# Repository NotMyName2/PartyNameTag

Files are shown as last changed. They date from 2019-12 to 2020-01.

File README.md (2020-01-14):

# PartyNameTag

Remember the nasty sticky paper name tags probably used at parties? Never been to any party, so I do not. Anyway, once I figure out how to put this thingy on a shirt, it can be used as a name tag.

The device can display any reasonably long message consisting of the characters in the English alphabet sent by Bluetooth from any smartphone(tested only on android). The text shifts in the same way like a "breaking news" row in the news.

In the future, I might add more functionality:

 	 *display a hard-coded message after a certain period of inactivity
        (You can ask for a girl's number this way :O )

  	*display random noise(partially done)

  	*up- and down-shifting

  	*finish the character lookup table

  	*implement the LED indicator for low battery

  	*display special emoji or animations

The thingy is based on Arduino Pro Mini, an AT09 Bluetooth module, a TC4056 Li-ion charger module, an old phone battery, 74HC595 shift registers, a DC-DC 5V voltage supply and many unipolar transistors.

The microcontroller can be easily reprogrammed using the Arduino IDE and a USB to Serial converter.

The custom PCB is in the "DivineMessengerBoard" directory. The smallest track width is 0.4mm and the smallest clearance is 0.2mm and is meant to be manufactured professionally (DIY drill or UV would probably bring frustration)

See the video at https://youtu.be/IolG6l6WMoY

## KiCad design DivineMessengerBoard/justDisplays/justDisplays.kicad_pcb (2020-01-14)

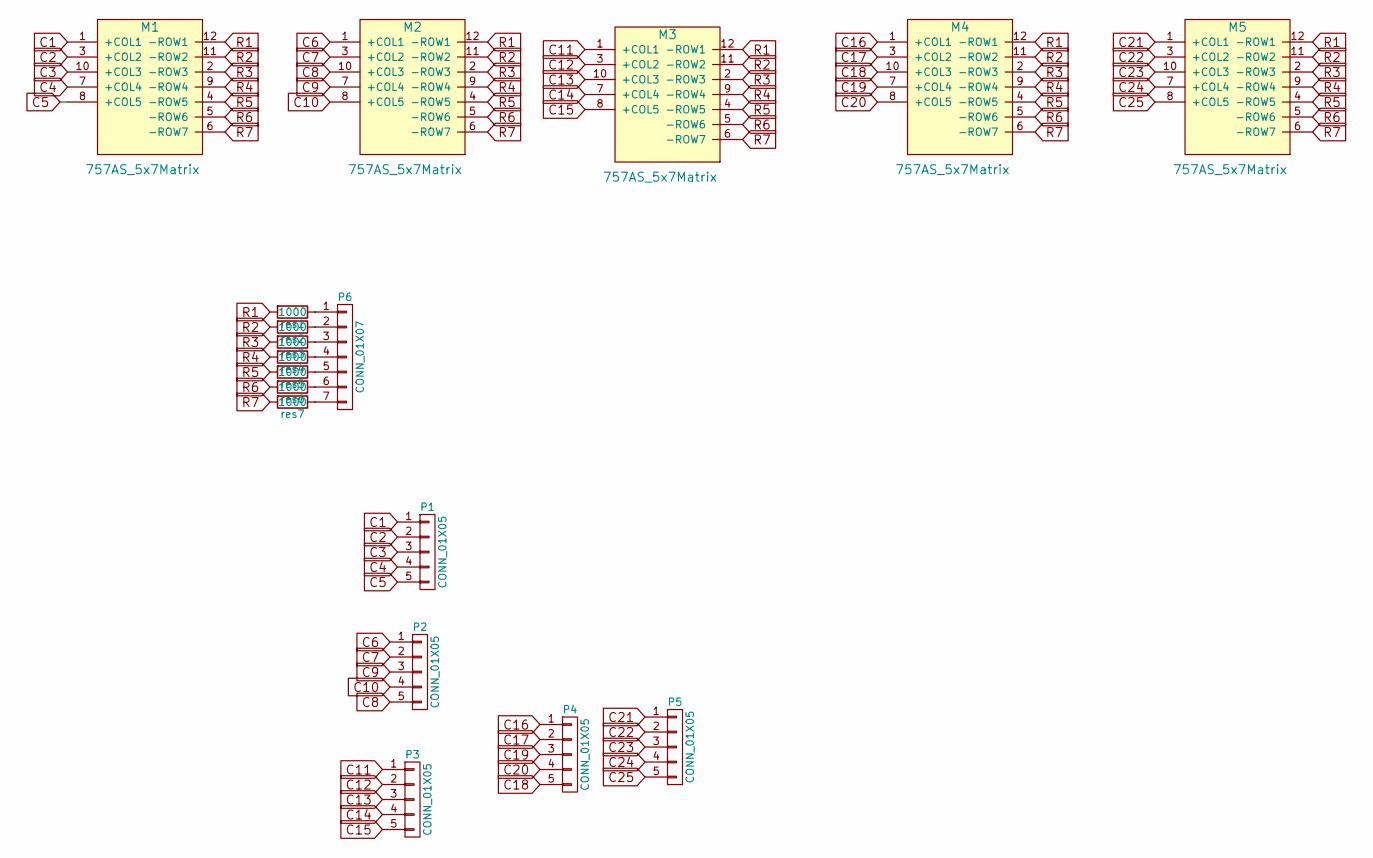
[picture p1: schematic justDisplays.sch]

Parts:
M1, M2, M3, M4, M5: 757AS_5x7Matrix; 757-5x7Matrix-socket
P1, P2, P3, P4, P5: CONN_01X05; NonRetardHeader1x5
P6: CONN_01X07; NonRetardHeader1x7
res1, res2, res3, res4, res5, res6, res7: 1000; R_1206_HandSoldering

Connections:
C1: M1.1 (+COL1), P1.1
C2: M1.3 (+COL2), P1.2
C3: M1.10 (+COL3), P1.3
C4: M1.7 (+COL4), P1.4
C5: M1.8 (+COL5), P1.5
C6: M2.1 (+COL1), P2.1
C7: M2.3 (+COL2), P2.2
C8: M2.10 (+COL3), P2.5
C9: M2.7 (+COL4), P2.3
C10: M2.8 (+COL5), P2.4
C11: M3.1 (+COL1), P3.1
C12: M3.3 (+COL2), P3.2
C13: M3.10 (+COL3), P3.3
C14: M3.7 (+COL4), P3.4
C15: M3.8 (+COL5), P3.5
C16: M4.1 (+COL1), P4.1
C17: M4.3 (+COL2), P4.2
C18: M4.10 (+COL3), P4.5
C19: M4.7 (+COL4), P4.3
C20: M4.8 (+COL5), P4.4
C21: M5.1 (+COL1), P5.1
C22: M5.3 (+COL2), P5.2
C23: M5.10 (+COL3), P5.3
C24: M5.7 (+COL4), P5.4
C25: M5.8 (+COL5), P5.5
unnamed: P6.1, res1.1
unnamed: P6.2, res2.1
unnamed: P6.3, res3.1
unnamed: P6.4, res4.1
unnamed: P6.5, res5.1
unnamed: P6.6, res6.1
unnamed: P6.7, res7.1
R1: M1.12 (-ROW1), M2.12 (-ROW1), M3.12 (-ROW1), M4.12 (-ROW1), M5.12 (-ROW1), res1.2
R2: M1.11 (-ROW2), M2.11 (-ROW2), M3.11 (-ROW2), M4.11 (-ROW2), M5.11 (-ROW2), res2.2
R3: M1.2 (-ROW3), M2.2 (-ROW3), M3.2 (-ROW3), M4.2 (-ROW3), M5.2 (-ROW3), res3.2
R4: M1.9 (-ROW4), M2.9 (-ROW4), M3.9 (-ROW4), M4.9 (-ROW4), M5.9 (-ROW4), res4.2
R5: M1.4 (-ROW5), M2.4 (-ROW5), M3.4 (-ROW5), M4.4 (-ROW5), M5.4 (-ROW5), res5.2
R6: M1.5 (-ROW6), M2.5 (-ROW6), M3.5 (-ROW6), M4.5 (-ROW6), M5.5 (-ROW6), res6.2
R7: M1.6 (-ROW7), M2.6 (-ROW7), M3.6 (-ROW7), M4.6 (-ROW7), M5.6 (-ROW7), res7.2

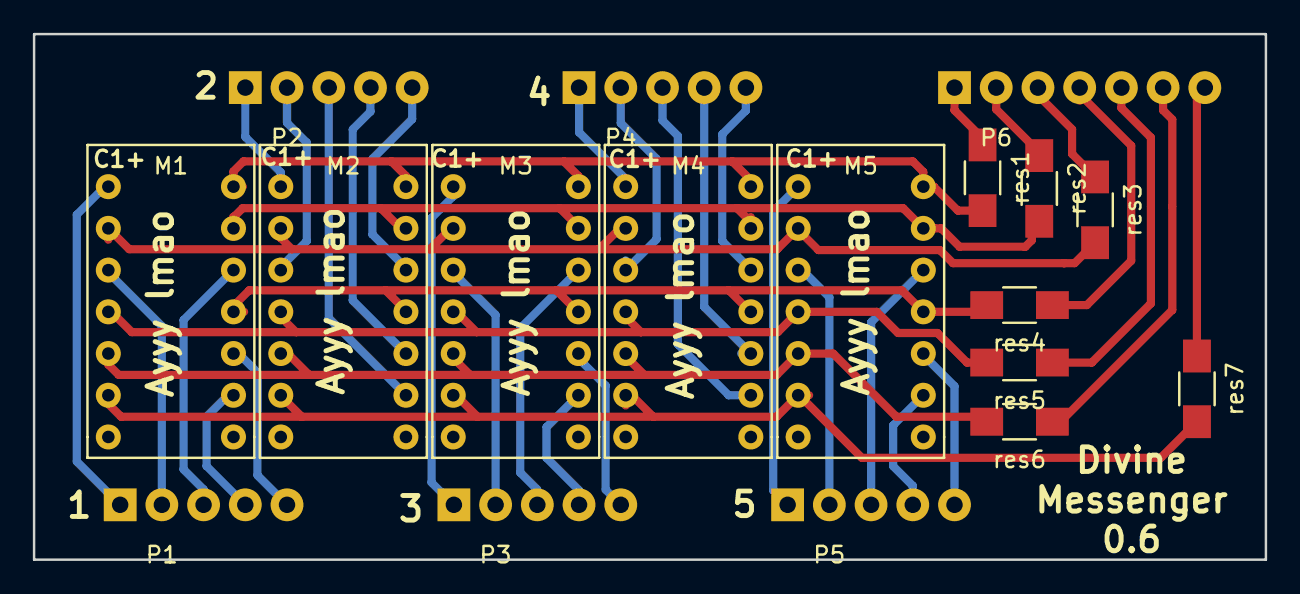
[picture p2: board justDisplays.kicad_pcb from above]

Board: 2 copper layers, 75.0 x 32.0 mm, 18 parts (0 on the bottom side), 39 nets.

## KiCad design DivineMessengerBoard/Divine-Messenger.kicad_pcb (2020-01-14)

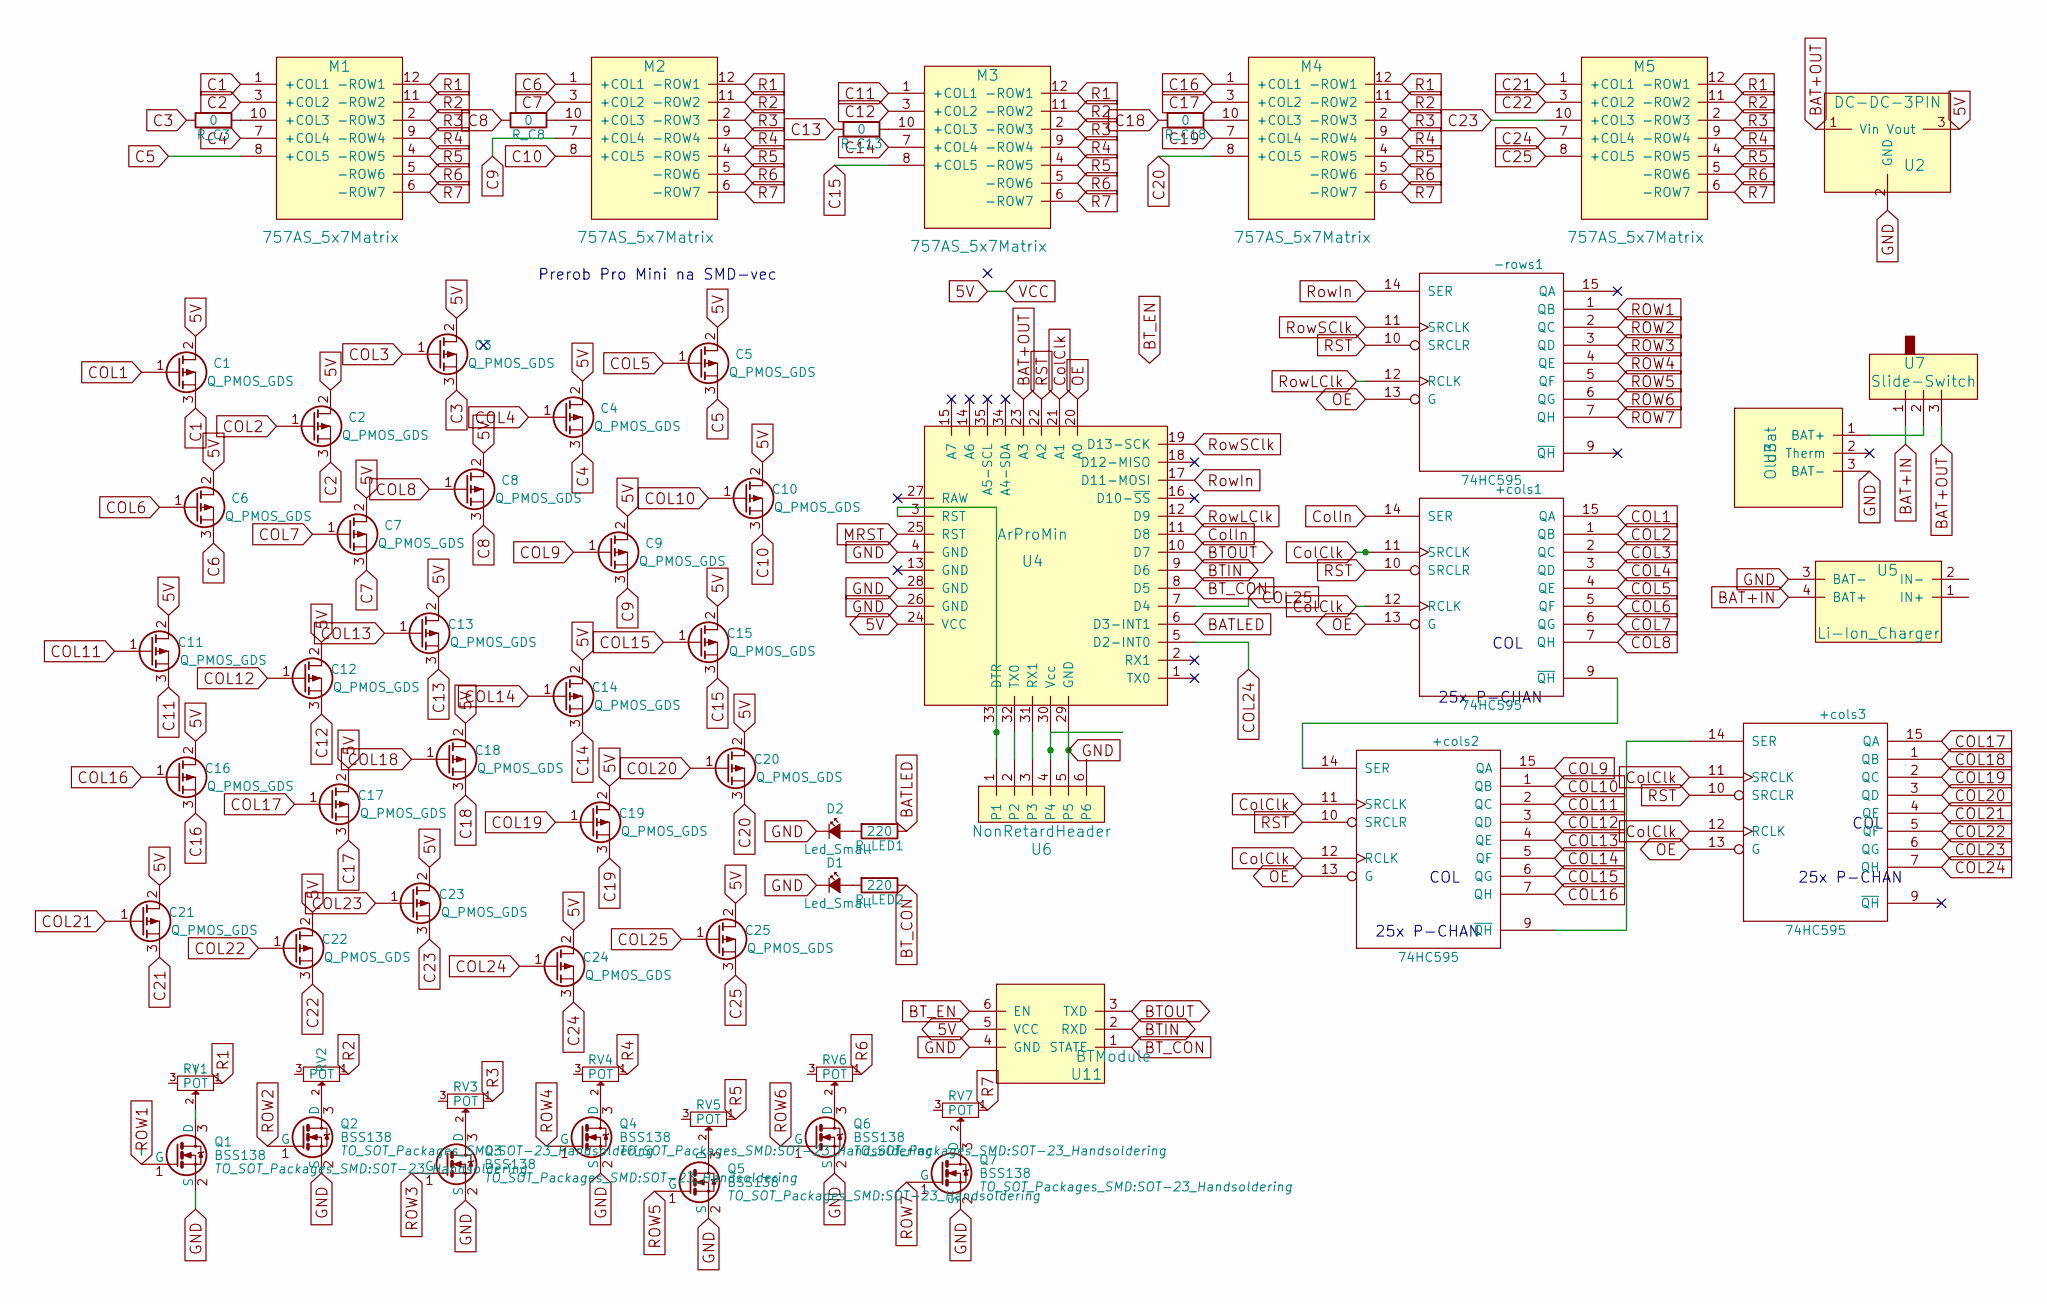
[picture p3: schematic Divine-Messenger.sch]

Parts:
+cols1, +cols2, +cols3: 74HC595; SOIC-16_3.9x9.9mm_Pitch1.27mm
-rows1: 74HC595; SOIC-16_3.9x9.9mm_Pitch1.27mm
C1, C2, C3, C4, C5, C6, C7, C8, C9, C10, C11, C12, C13, C14, C15, C16, C17, C18, C19, C20, C21, C22, C23, C24, C25: Q_PMOS_GDS; SOT-23_Handsoldering
D1, D2: Led_Small; LED-3MM
M1, M2, M3, M4, M5: 757AS_5x7Matrix; 757-5x7Matrix
Q1, Q2, Q3, Q4, Q5, Q6, Q7: BSS138; SOT-23_Handsoldering
RV1, RV2, RV3, RV4, RV5, RV6, RV7: POT; SMD-Trimm
R_C3, R_C8, R_C13, R_C18: 0; R_1206_HandSoldering
R_LED1, R_LED2: 220; R_0805_HandSoldering
U2: DC-DC-3PIN; NonRetardHeader1x3
U3: OldBat; oldBatTHT
U4: ArProMin; ProMiniSMDNoWeirdAndRxTxPinsLongPads
U5: Li-Ion_Charger; Li-Ion-charger1-SMD-LongPads
U6: NonRetardHeader; NonRetardHeader1x6
U7: Slide-Switch
U11: BTModule; BtModuleSMDLongPads

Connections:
5V: -rows1.16 (VCC), C1.2 (D), C2.2 (D), C3.2 (D), C4.2 (D), C5.2 (D), C6.2 (D), C7.2 (D), C8.2 (D), C9.2 (D), C10.2 (D), C11.2 (D), C12.2 (D), C13.2 (D), C14.2 (D), C15.2 (D), C16.2 (D), C17.2 (D), C18.2 (D), C19.2 (D), C20.2 (D), C21.2 (D), C22.2 (D), C23.2 (D), C24.2 (D), C25.2 (D), U2.3 (Vout), U4.24 (VCC), U11.5 (VCC); also elsewhere on the board
BAT+IN: U5.4 (BAT+), U7.1
BAT+OUT: U2.1 (Vin), U4.23 (A3), U7.3
BATLED: R_LED1.1, U4.6 (D3-INT1)
BTIN: U4.9 (D6), U11.2 (RXD)
BTOUT: U4.10 (D7), U11.3 (TXD)
BT_CON: R_LED2.1, U4.8 (D5), U11.1 (STATE)
C1: C1.3 (S), M1.1 (+COL1)
C2: C2.3 (S), M1.3 (+COL2)
C3: C3.3 (S), R_C3.2
C4: C4.3 (S), M1.7 (+COL4)
C5: C5.3 (S), M1.8 (+COL5)
C6: C6.3 (S), M2.1 (+COL1)
C7: C7.3 (S), M2.3 (+COL2)
C8: C8.3 (S), R_C8.2
C9: C9.3 (S), M2.7 (+COL4)
C10: C10.3 (S), M2.8 (+COL5)
C11: C11.3 (S), M3.1 (+COL1)
C12: C12.3 (S), M3.3 (+COL2)
C13: C13.3 (S), R_C13.2
C14: C14.3 (S), M3.7 (+COL4)
C15: C15.3 (S), M3.8 (+COL5)
C16: C16.3 (S), M4.1 (+COL1)
C17: C17.3 (S), M4.3 (+COL2)
C18: C18.3 (S), R_C18.2
C19: C19.3 (S), M4.7 (+COL4)
C20: C20.3 (S), M4.8 (+COL5)
C21: C21.3 (S), M5.1 (+COL1)
C22: C22.3 (S), M5.3 (+COL2)
C23: C23.3 (S), M5.10 (+COL3)
C24: C24.3 (S), M5.7 (+COL4)
C25: C25.3 (S), M5.8 (+COL5)
COL1: +cols1.15 (QA), C1.1 (G); also elsewhere on the board
COL2: +cols1.1 (QB), C2.1 (G); also elsewhere on the board
COL3: +cols1.2 (QC), C3.1 (G); also elsewhere on the board
COL4: +cols1.3 (QD), C4.1 (G); also elsewhere on the board
COL5: +cols1.4 (QE), C5.1 (G); also elsewhere on the board
COL6: +cols1.5 (QF), C6.1 (G); also elsewhere on the board
COL7: +cols1.6 (QG), C7.1 (G); also elsewhere on the board
COL8: +cols1.7 (QH), C8.1 (G); also elsewhere on the board
COL9: +cols2.15 (QA), C9.1 (G); also elsewhere on the board
COL10: +cols2.1 (QB), C10.1 (G); also elsewhere on the board
COL11: +cols2.2 (QC), C11.1 (G); also elsewhere on the board
COL12: +cols2.3 (QD), C12.1 (G); also elsewhere on the board
COL13: +cols2.4 (QE), C13.1 (G); also elsewhere on the board
COL14: +cols2.5 (QF), C14.1 (G); also elsewhere on the board
COL15: +cols2.6 (QG), C15.1 (G); also elsewhere on the board
COL16: +cols2.7 (QH), C16.1 (G); also elsewhere on the board
COL17: +cols3.15 (QA), C17.1 (G); also elsewhere on the board
COL18: +cols3.1 (QB), C18.1 (G); also elsewhere on the board
COL19: +cols3.2 (QC), C19.1 (G); also elsewhere on the board
COL20: +cols3.3 (QD), C20.1 (G); also elsewhere on the board
COL21: +cols3.4 (QE), C21.1 (G); also elsewhere on the board
COL22: +cols3.5 (QF), C22.1 (G); also elsewhere on the board
COL23: +cols3.6 (QG), C23.1 (G); also elsewhere on the board
COL24: +cols3.7 (QH), C24.1 (G), U4.5 (D2-INT0); also elsewhere on the board
COL25: C25.1 (G), U4.7 (D4)
ColClk: +cols1.11 (SRCLK), +cols1.12 (RCLK), +cols2.11 (SRCLK), +cols2.12 (RCLK), +cols3.11 (SRCLK), +cols3.12 (RCLK), U4.21 (A1); also elsewhere on the board
ColIn: +cols1.14 (SER), U4.11 (D8); also elsewhere on the board
GND: -rows1.8 (GND), D1.1 (K), D2.1 (K), Q1.2 (S), Q2.2 (S), Q3.2 (S), Q4.2 (S), Q5.2 (S), Q6.2 (S), Q7.2 (S), U2.2 (GND), U3.3 (BAT-), U4.4 (GND), U4.26 (GND), U4.28 (GND), U4.29 (GND), U5.3 (BAT-), U6.5, U11.4 (GND); also elsewhere on the board
unnamed 60: +cols1.9 (~QH), +cols2.14 (SER); also elsewhere on the board
unnamed 61: +cols2.9 (~QH), +cols3.14 (SER); also elsewhere on the board
unnamed: D1.2 (A), R_LED2.2
unnamed: D2.2 (A), R_LED1.2
unnamed: M1.10 (+COL3), R_C3.1
unnamed: M2.10 (+COL3), R_C8.1
unnamed: M3.10 (+COL3), R_C13.1
unnamed: M4.10 (+COL3), R_C18.1
unnamed: Q1.3 (D), RV1.2
unnamed: Q2.3 (D), RV2.2
unnamed: Q3.3 (D), RV3.2
unnamed: Q4.3 (D), RV4.2
unnamed: Q5.3 (D), RV5.2
unnamed: Q6.3 (D), RV6.2
unnamed: Q7.3 (D), RV7.2
unnamed: U3.1 (BAT+), U7.2
unnamed: U4.3 (RST), U4.33 (DTR), U6.1
unnamed: U4.30 (Vcc), U6.4
unnamed: U4.31 (RX1), U6.3
unnamed: U4.32 (TX0), U6.2
OE: +cols1.13 (G), +cols2.13 (G), +cols3.13 (G), -rows1.13 (G), U4.20 (A0); also elsewhere on the board
R1: M1.12 (-ROW1), M2.12 (-ROW1), M3.12 (-ROW1), M4.12 (-ROW1), M5.12 (-ROW1), RV1.1
R2: M1.11 (-ROW2), M2.11 (-ROW2), M3.11 (-ROW2), M4.11 (-ROW2), M5.11 (-ROW2), RV2.1
R3: M1.2 (-ROW3), M2.2 (-ROW3), M3.2 (-ROW3), M4.2 (-ROW3), M5.2 (-ROW3), RV3.1
R4: M1.9 (-ROW4), M2.9 (-ROW4), M3.9 (-ROW4), M4.9 (-ROW4), M5.9 (-ROW4), RV4.1
R5: M1.4 (-ROW5), M2.4 (-ROW5), M3.4 (-ROW5), M4.4 (-ROW5), M5.4 (-ROW5), RV5.1
R6: M1.5 (-ROW6), M2.5 (-ROW6), M3.5 (-ROW6), M4.5 (-ROW6), M5.5 (-ROW6), RV6.1
R7: M1.6 (-ROW7), M2.6 (-ROW7), M3.6 (-ROW7), M4.6 (-ROW7), M5.6 (-ROW7), RV7.1
ROW1: -rows1.1 (QB), Q1.1 (G)
ROW2: -rows1.2 (QC), Q2.1 (G)
ROW3: -rows1.3 (QD), Q3.1 (G)
ROW4: -rows1.4 (QE), Q4.1 (G)
ROW5: -rows1.5 (QF), Q5.1 (G)
ROW6: -rows1.6 (QG), Q6.1 (G)
ROW7: -rows1.7 (QH), Q7.1 (G)
RST: +cols1.10 (SRCLR), +cols2.10 (SRCLR), +cols3.10 (SRCLR), -rows1.10 (SRCLR), U4.22 (A2); also elsewhere on the board
RowIn: -rows1.14 (SER), U4.17 (D11-MOSI)
RowLClk: -rows1.12 (RCLK), U4.12 (D9)
RowSClk: -rows1.11 (SRCLK), U4.19 (D13-SCK)

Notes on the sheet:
COL
25x P-CHAN
Prerob Pro Mini na SMD-vec

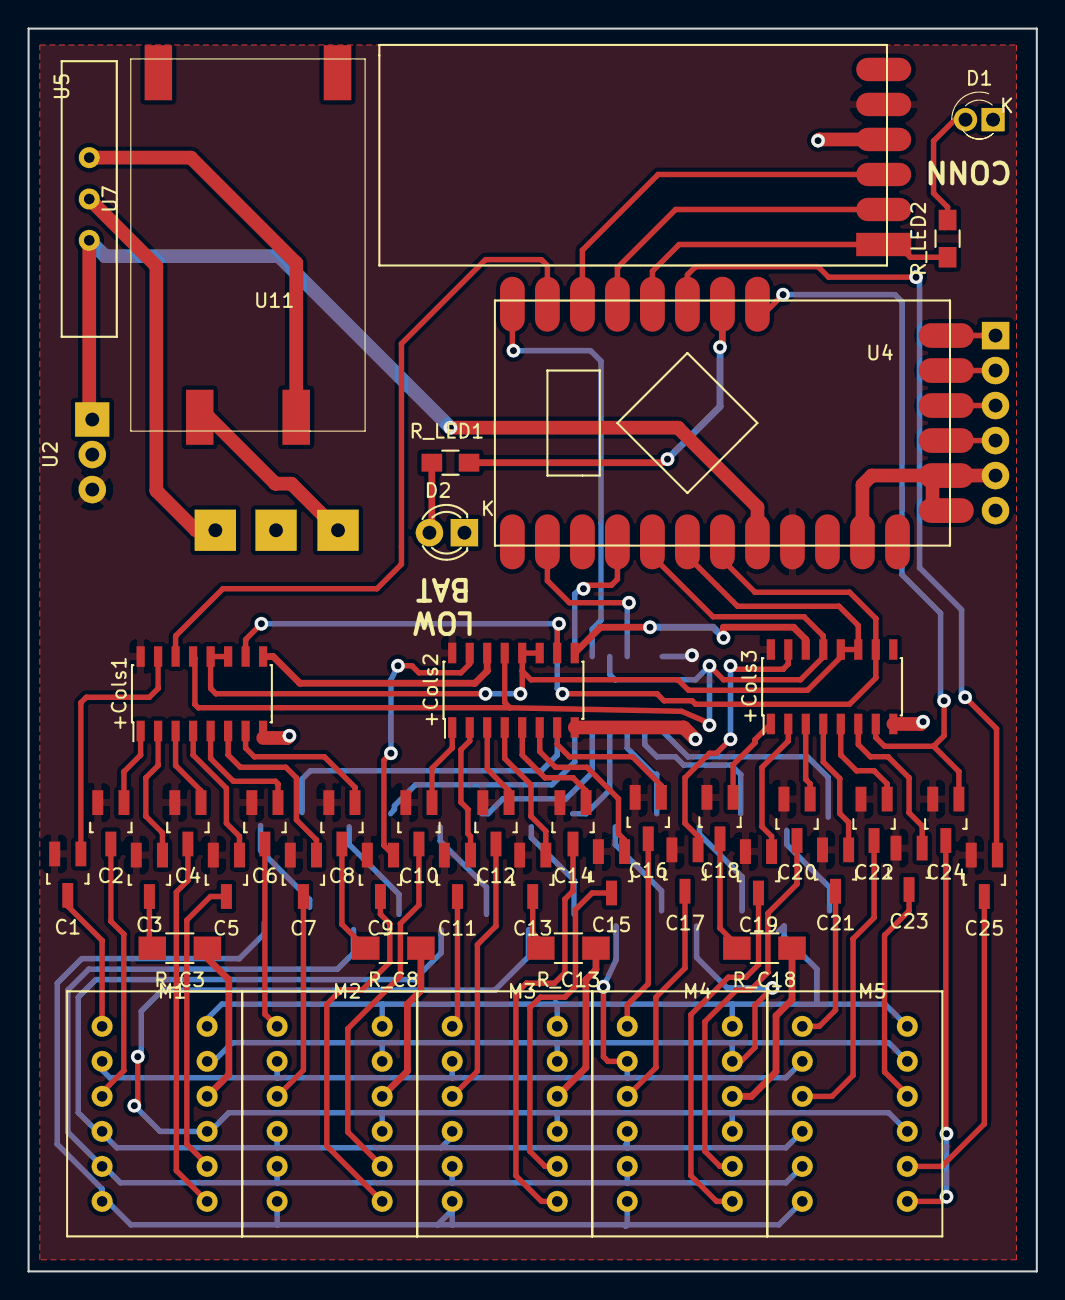
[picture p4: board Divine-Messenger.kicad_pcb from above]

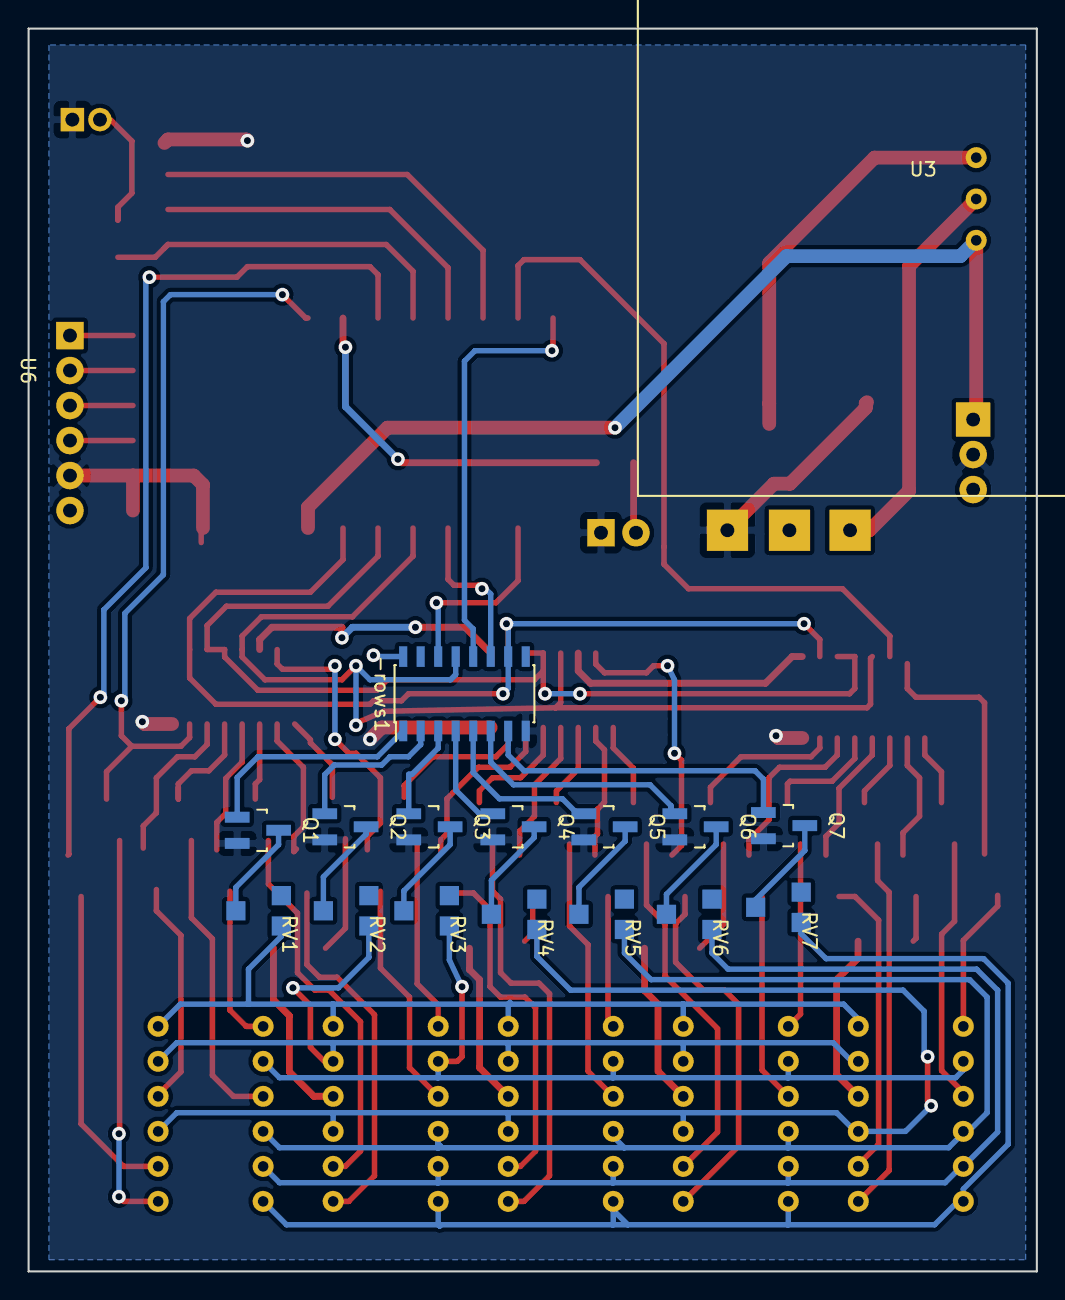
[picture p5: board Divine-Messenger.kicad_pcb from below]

Board: 2 copper layers, 73.2 x 90.2 mm, 63 parts (17 on the bottom side), 99 nets.

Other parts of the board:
+Cols1, +Cols2, +Cols3: 74HC595; SOIC-16_3.9x9.9mm_Pitch1.27mm

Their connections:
5V: +Cols1.16, +Cols2.16, +Cols3.16; also elsewhere on the board
COL1: +Cols1.15; also elsewhere on the board
COL2: +Cols1.1; also elsewhere on the board
COL3: +Cols1.2; also elsewhere on the board
COL4: +Cols1.3; also elsewhere on the board
COL5: +Cols1.4; also elsewhere on the board
COL6: +Cols1.5; also elsewhere on the board
COL7: +Cols1.6; also elsewhere on the board
COL8: +Cols1.7; also elsewhere on the board
COL9: +Cols2.15; also elsewhere on the board
COL10: +Cols2.1; also elsewhere on the board
COL11: +Cols2.2; also elsewhere on the board
COL12: +Cols2.3; also elsewhere on the board
COL13: +Cols2.4; also elsewhere on the board
COL14: +Cols2.5; also elsewhere on the board
COL15: +Cols2.6; also elsewhere on the board
COL16: +Cols2.7; also elsewhere on the board
COL17: +Cols3.15; also elsewhere on the board
COL18: +Cols3.1; also elsewhere on the board
COL19: +Cols3.2; also elsewhere on the board
COL20: +Cols3.3; also elsewhere on the board
COL21: +Cols3.4; also elsewhere on the board
COL22: +Cols3.5; also elsewhere on the board
COL23: +Cols3.6; also elsewhere on the board
COL24: +Cols3.7; also elsewhere on the board
ColClk: +Cols1.11, +Cols1.12, +Cols2.11, +Cols2.12, +Cols3.11, +Cols3.12; also elsewhere on the board
ColIn: +Cols1.14; also elsewhere on the board
GND: +Cols1.8, +Cols2.8, +Cols3.8; also elsewhere on the board
unnamed 60: +Cols1.9, +Cols2.14; also elsewhere on the board
unnamed 61: +Cols2.9, +Cols3.14; also elsewhere on the board
OE: +Cols1.13, +Cols2.13, +Cols3.13; also elsewhere on the board
RST: +Cols1.10, +Cols2.10, +Cols3.10; also elsewhere on the board

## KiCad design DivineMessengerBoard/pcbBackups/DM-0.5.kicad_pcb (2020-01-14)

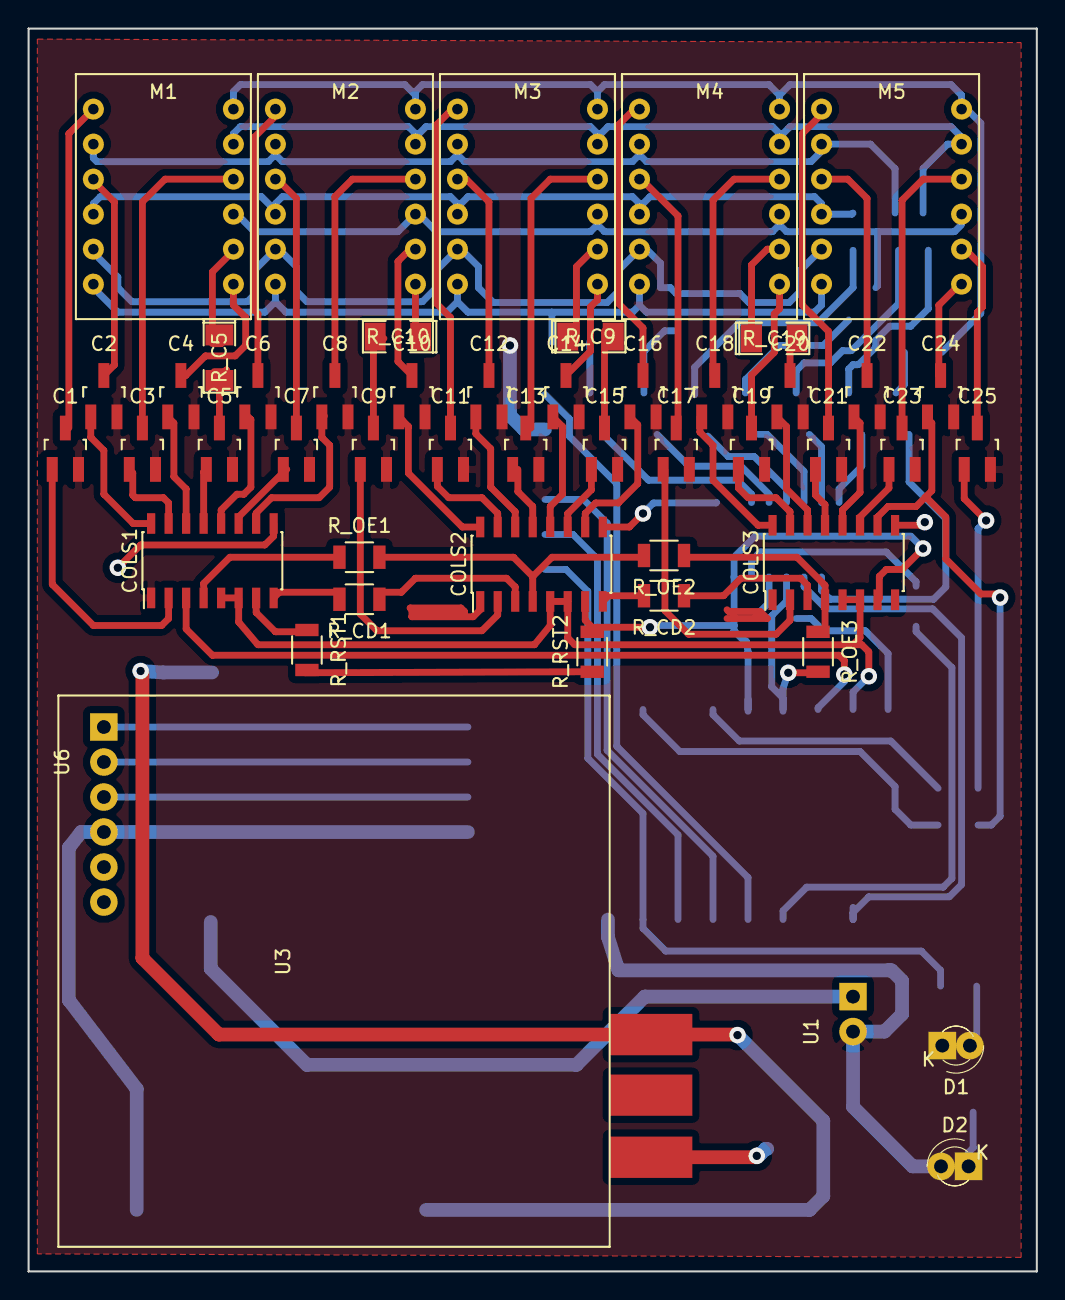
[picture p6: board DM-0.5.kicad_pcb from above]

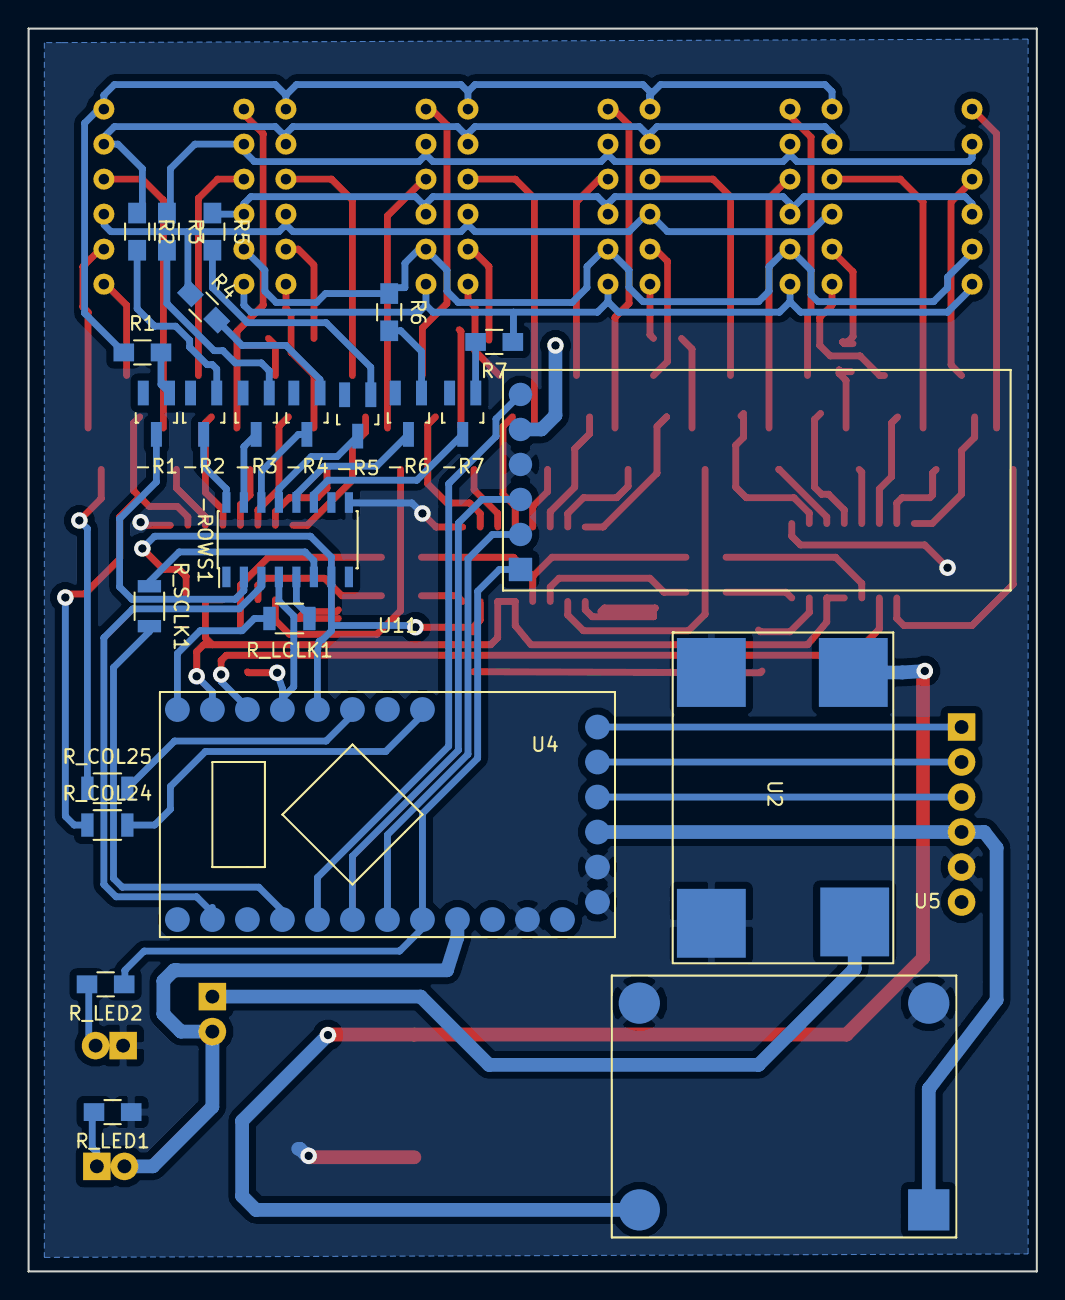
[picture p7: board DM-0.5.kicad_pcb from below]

Board: 2 copper layers, 73.2 x 90.2 mm, 74 parts (25 on the bottom side), 109 nets.

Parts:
-R1, -R2, -R3, -R4, -R5, -R6, -R7: Q_NMOS_DSG; SOT-23_Handsoldering
-ROWS1: 74HC595-F; SOIC-16_3.9x9.9mm_Pitch1.27mm
C1, C2, C3, C4, C5, C6, C7, C8, C9, C10, C11, C12, C13, C14, C15, C16, C17, C18, C19, C20, C21, C22, C23, C24, C25: Q_PMOS_GDS; SOT-23_Handsoldering
COLS1, COLS2, COLS3: 74HC595-F; SOIC-16_3.9x9.9mm_Pitch1.27mm
D1, D2: Led_Small; LED-3MM
M1, M2, M3, M4, M5: 757AS_5x7Matrix; 757-5x7Matrix
R1, R2, R3, R4, R5, R6, R7: 220; R_0805_HandSoldering
R_C5, R_C9, R_C10, R_C19: 0; SMD-1206_Pol
R_CD1, R_CD2: 0; R_1206
R_COL24, R_COL25: 0; R_1206
R_LCLK1: 0; R_1206
R_LED1, R_LED2: 220; R_0805_HandSoldering
R_OE1, R_OE2, R_OE3: 0; R_1206
R_RST1, R_RST2: 0; R_1206
R_SCLK1: 0; R_1206
U1: NonRetardHeader1x2
U2: DC-DC
U3: OldBat; DC-DC
U4: ArProMin; ProMiniSMDNoWeirdAndRxTxPins
U5: Li-Ion_Charger; Li-Ion-charger2-SMD
U6: NonRetardHeader; NonRetardHeader1x6
U11: BTModule; BtModuleSMD

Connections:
5V: C1.2, C2.2, C3.2, C4.2, C5.2, C6.2, C7.2, C8.2, C9.2, C10.2, C11.2, C12.2, C13.2, C14.2, C15.2, C16.2, C17.2, C18.2, C19.2, C20.2, C21.2, C22.2, C23.2, C24.2, C25.2, COLS1.1, D2.2, U1.2, U4.24, U11.5
BAT+: U2.1, U3.1, U5.4
BTIN: U4.22, U11.2
BTOUT: U4.21, U11.3
BT_CON: R_LED2.1, U4.23, U11.1
BT_EN: U4.20, U11.6
C1: C1.3, M1.1
C2: C2.3, M1.3
C3: C3.3, M1.10
C4: C4.3, M1.7
C5: C5.3, R_C5.2
C6: C6.3, M2.1
C7: C7.3, M2.3
C8: C8.3, M2.10
C9: C9.3, R_C10.2
C10: C10.3, M2.8
C11: C11.3, M3.1
C12: C12.3, M3.3
C13: C13.3, M3.10
C14: C14.3, M3.7
C15: C15.3, R_C9.2
C16: C16.3, M4.1
C17: C17.3, M4.3
C18: C18.3, M4.10
C19: C19.3, M4.7
C20: C20.3, R_C19.2
C21: C21.3, M5.1
C22: C22.3, M5.3
C23: C23.3, M5.10
C24: C24.3, M5.7
C25: C25.3, M5.8
CHRGR: U4.30, U5.1, U6.4
COL1: C1.1, COLS1.2
COL2: C2.1, COLS1.16
COL3: C3.1, COLS1.15
COL4: C4.1, COLS1.14
COL5: C5.1, COLS1.13
COL6: C6.1, COLS1.12
COL7: C7.1, COLS1.11
COL8: C8.1, COLS1.10
COL9: C9.1, COLS2.2
COL10: C10.1, COLS2.16
COL11: C11.1, COLS2.15
COL12: C12.1, COLS2.14
COL13: C13.1, COLS2.13
COL14: C14.1, COLS2.12
COL15: C15.1, COLS2.11
COL16: C16.1, COLS2.10
COL17: C17.1, COLS3.2
COL18: C18.1, COLS3.16
COL19: C19.1, COLS3.15
COL20: C20.1, COLS3.14
COL21: C21.1, COLS3.13
COL22: C22.1, COLS3.12
COL23: C23.1, COLS3.11
COL24: C24.1, COLS3.10, R_COL24.1
COL25: C25.1, R_COL25.1
ColClk: COLS1.5, COLS1.6, COLS2.5, COLS2.6, COLS3.5, COLS3.6, U4.11
ColIn: COLS1.3, U4.10
GND: -ROWS1.9, COLS1.9, COLS2.9, COLS3.9, D1.1, R_LED1.1, U2.2, U2.3, U3.3, U4.26, U4.28, U4.29, U5.2, U5.3, U6.5, U11.4
unnamed: -R1.1, R1.2
unnamed: -R2.1, R2.2
unnamed: -R3.1, R3.2
unnamed: -R4.1, R4.2
unnamed: -R5.1, R5.2
unnamed: -R6.1, R6.2
unnamed: -R7.1, R7.2
unnamed: -ROWS1.5, R_LCLK1.1
unnamed: -ROWS1.6, R_SCLK1.1
unnamed: COLS1.4, R_OE1.1
unnamed: COLS1.7, R_RST1.1
unnamed: COLS1.8, R_CD1.2
unnamed: COLS2.3, R_CD1.1
unnamed: COLS2.4, R_OE1.2, R_OE2.2
unnamed: COLS2.8, R_CD2.2
unnamed: COLS3.3, R_CD2.1
unnamed: COLS3.4, R_OE2.1, R_OE3.1
unnamed: D1.2, R_LED2.2
unnamed: D2.1, R_LED1.2
unnamed: M1.8, R_C5.1
unnamed: M2.7, R_C10.1
unnamed: M3.8, R_C9.1
unnamed: M4.8, R_C19.1
unnamed: R_COL24.2, U4.5
unnamed: R_COL25.2, U4.7
unnamed: R_RST1.2, R_RST2.1
unnamed: U4.33, U6.1
unnamed: U4.31, U6.3
unnamed: U4.32, U6.2
OE: -ROWS1.4, R_OE3.2, U4.9
Pow: U1.1, U2.4
R1: M1.12, M2.12, M3.12, M4.12, M5.12, R1.1
R2: M1.11, M2.11, M3.11, M4.11, M5.11, R2.1
R3: M1.2, M2.2, M3.2, M4.2, M5.2, R3.1
R4: M1.9, M2.9, M3.9, M4.9, M5.9, R4.1
R5: M1.4, M2.4, M3.4, M4.4, M5.4, R5.1
R6: M1.5, M2.5, M3.5, M4.5, M5.5, R6.1
R7: M1.6, M2.6, M3.6, M4.6, M5.6, R7.1
ROW1: -R1.3, -ROWS1.2
ROW2: -R2.3, -ROWS1.16
ROW3: -R3.3, -ROWS1.15
ROW4: -R4.3, -ROWS1.14
ROW5: -R5.3, -ROWS1.13
ROW6: -R6.3, -ROWS1.12
ROW7: -R7.3, -ROWS1.11
RST: -ROWS1.7, COLS2.7, COLS3.7, R_RST2.2, U4.8
RowIn: -ROWS1.3, U4.17
RowLClk: R_LCLK1.2, U4.12
RowSClk: R_SCLK1.2, U4.19

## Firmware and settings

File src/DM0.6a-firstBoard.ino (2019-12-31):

/*
 *  Divine Messenger v0.6, Ivan Cermak 2016-2019
 *  uses Arduino Nano, 5x757AS 5x7 LED matrix and 3x74HC595 shift registers
 *  Two Shift registers drive transistors which drive columns, only one column is HIGH at a time, supply current and positive voltage (5 columns per one matrix)
 *  One Shift register drives transistors which drive rows and sinks current to ground (7 pins)
 *  displays recieved message
 *  can use Bluetooth when connected to HW serial pins
 *  has custom PCB from China
 *
 *
 *
 * PINS
 *
 *  Shift register for Rows
 *
 *    dataPin = D12; ->d11
 *    registerOutputEnable = D12;
 *    latchClk = D10;
 *    serClkPin = D9; ->d13
 *    resetPin = D8;
 *
 *  Shift registers for columns
 *
 *
 *
 *
 *
 *
 *    dataPin = D4;
 *    resetPin = D3;
 *    latClk = D5;
 *    serClk = D6;
 *    OutputEnable = D7
 *
 *
 *  TODO
 *
 *
 *    Rewrite lookup table
 *    special emojis
 *    up-down motion maybe
 *    battery indicator
*/

//****************** CONSTANTS & VARIABLES **************************

 #include <SPI.h>
#include <SoftwareSerial.h>
const uint8_t lookup[129][5]={{1, 1, 1, 1, 1},     //0 - not used
                   {127, 0, 127, 0, 127}, //1 stripes
                   {1, 1, 1, 1, 1},
                   {1, 1, 1, 1, 1},
                   {1, 1, 1, 1, 1},
                   {1, 1, 1, 1, 1},
                   {1, 1, 1, 1, 1},
                   {1, 1, 1, 1, 1},
                   {1, 1, 1, 1, 1},
                   {1, 1, 1, 1, 1},
                   {255, 255, 255, 255, 255},//10 all lit af
                   {1, 1, 1, 1, 1},
                   {1, 1, 1, 1, 1},
                   {1, 1, 1, 1, 1},
                   {1, 1, 1, 1, 1},
                   {1, 1, 1, 1, 1},
                   {1, 1, 1, 1, 1},
                   {1, 1, 1, 1, 1},
                   {1, 1, 1, 1, 1},
                   {1, 1, 1, 1, 1},
                   {1, 1, 1, 1, 1},//20
                   {18, 34, 44, 34, 16},    // winky smiley face
                   {12, 18, 36, 18, 12},         // empty heart
                   {12, 30, 60, 30, 12},         //full heart
                   {1, 1, 1, 1, 1},
                   {1, 1, 1, 1, 1},
                   {1, 1, 1, 1, 1},
                   {1, 1, 1, 1, 1},
                   {1, 1, 1, 1, 1},
                   {1, 1, 1, 1, 1},
                   {1, 1, 1, 1, 1},    //30
                   {1, 1, 1, 1, 1},
                   {0, 0, 0, 0, 0},    //SPACE
                   {1, 1, 1, 1, 1},
                   {1, 1, 1, 1, 1},
                   {1, 1, 1, 1, 1},
                   {1, 1, 1, 1, 1},
                   {1, 1, 1, 1, 1},
                   {1, 1, 1, 1, 1},
                   {1, 1, 1, 1, 1},
                   {1, 1, 1, 1, 1},    //40
                   {1, 1, 1, 1, 1},
                   {1, 1, 1, 1, 1},
                   {1, 1, 1, 1, 1},
                   {1, 1, 1, 1, 1},
                   {1, 1, 1, 1, 1},
                   {1, 1, 1, 1, 1},
                   {1, 1, 1, 1, 1},
                   {1, 1, 1, 1, 1},
                   {1, 1, 1, 1, 1},
                   {1, 1, 1, 1, 1},    //50
                   {1, 1, 1, 1, 1},
                   {1, 1, 1, 1, 1},
                   {1, 1, 1, 1, 1},
                   {1, 1, 1, 1, 1},
                   {1, 1, 1, 1, 1},
                   {1, 1, 1, 1, 1},
                   {1, 1, 1, 1, 1},
                   {0, 0, 36, 0, 0},    //:
                   {1, 1, 1, 1, 1},
                   {1, 1, 1, 1, 1},    //60
                   {1, 1, 1, 1, 1},
                   {1, 1, 1, 1, 1},
                   {1, 1, 1, 1, 1},
                   {1, 1, 1, 1, 1},
                   {126, 9, 9, 9, 126},        //A
                   {127, 73, 73, 73, 54},           //B
                   {62, 65, 65, 65, 34},          //C
                   {127, 65, 65, 34, 28},    //D
                   {127, 73, 73, 65, 65},    //E
                   {127, 9, 9, 9, 1},      //70 F
                   {62, 65, 73, 73, 48},    //G
                   {127, 8, 8, 8, 127},     //H
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
                   {18, 34, 44, 34, 16},    // winky smiley face
                   {12, 18, 36, 18, 12},         // empty heart
                   {12, 30, 60, 30, 12},         //full heart
                   {1, 1, 1, 1, 1},
                   {1, 1, 1, 1, 1},
                   {1, 1, 1, 1, 1},
                   {48, 72, 68, 68, 124},   //a
                   {127, 68, 68, 68, 56},   //b
                   {56, 68, 68, 40, 0},     //c
                   {1, 1, 1, 1, 1},    //100
                   {4, 0, 0, 0, 0},
                   {5, 0, 0, 0, 0},
                   {6, 0, 0, 0, 0},
                   {7, 0, 0, 0, 0},
                   {0, 64, 122, 0, 0},    //i
                   {9, 0, 0, 0, 0},
                   {127, 16, 40, 72, 0},  //k
                   {11, 0, 0, 2, 1},
                   {12, 0, 0, 2, 1},
                   {124, 8, 4, 4, 120},    //110 n
                   {56, 68, 68, 68, 56},    //o
                   {1, 1, 1, 1, 1},
                   {16, 0, 0, 0, 0},
                   {124, 8, 4, 4, 8},       //r
                   {18, 0, 0, 0, 0},
                   {9, 63, 8, 67, 0},       //makke t
                   {60, 64, 66, 65, 60},        //dlhe u
                   {60, 64, 64, 64, 60},        //kratke u
                   {9, 63, 8, 67, 0},           //makke t
                   {1, 1, 1, 1, 1},    //120
                   {1, 1, 1, 1, 1},
                   {1, 1, 1, 1, 1},
                   {1, 1, 1, 1, 1},
                   {1, 1, 1, 1, 1},
                   {1, 1, 1, 1, 1},
                   {1, 1, 1, 1, 1},
                   {1, 1, 1, 1, 1},
                   {1, 1, 1, 1, 1}};    //128


//ROWS
const int rowSerClkPin = 13;
const int rowDataPin = 11;
const int rowLatClkPin = 9;
const int rowOutputEnable = A0;
const int rowResetPin = A2;

//COLUMNS

const int colDataPin = 8;
const int colResetPin = A2;
const int colLatClkPin = A1;
const int colSerClkPin = A1;
const int colOutputEnable = A0;

const int amountOfDisplays =5;//5x7 displays
const int amountOfRows=7;
const int amountOfColumns=5;
const int amountOfDisplayColumns = amountOfDisplays*amountOfColumns;




//***************** FUNCTIONS *******************

void resetRows()
{
  digitalWrite(rowResetPin, HIGH);
  digitalWrite(rowResetPin, LOW);
  digitalWrite(rowResetPin, HIGH);
}

void resetColumns()
{

  digitalWrite(colResetPin, HIGH);
  digitalWrite(colResetPin, LOW);
  digitalWrite(colResetPin, HIGH);
}

void resetRegisters()
{
  Serial.println("reset");
  resetRows();
  resetColumns();
}


void sendRowData(int data)    //for advancing rows
{
  if(data>0)
  {
    digitalWrite(rowDataPin, HIGH);
  }
  else
  {
    digitalWrite(rowDataPin, LOW);
  }
  digitalWrite(rowSerClkPin, LOW);
  digitalWrite(rowSerClkPin, HIGH);
  digitalWrite(rowDataPin, LOW);
}

void sendColClock()
{
  digitalWrite(colSerClkPin, LOW);
  digitalWrite(colSerClkPin, HIGH);
}


void sendRowLatch()
{
  digitalWrite(rowLatClkPin, LOW);
  digitalWrite(rowLatClkPin, HIGH);
}

void sendColLatch()
{
  digitalWrite(colLatClkPin, LOW);
  digitalWrite(colLatClkPin, HIGH);
}

void resetPins()
{
  Serial.println("RESET PINS/REGISTERS");
  resetRegisters();

}

void enableAllOutputs(bool enabled)
{
  if(enabled)
  {
    digitalWrite(rowOutputEnable, LOW); //LOW = displays on
    digitalWrite(colOutputEnable, LOW);
  }
  else
  {
    digitalWrite(rowOutputEnable, HIGH);
    digitalWrite(colOutputEnable, HIGH);
  }

}

void startColumns()
{
  //Serial.println("starting columns");
  digitalWrite(colDataPin, LOW);
  sendColClock();
  digitalWrite(colDataPin, HIGH);
}

//*************** HW functions end *********************


//***************   SHIFTING FUNCTIONS  begin************

const uint8_t bufferSize = 6;
uint8_t bufferRunner = 0;
uint8_t messageRunner = 0;
bool needsInput = true;

uint8_t message[100];
uint8_t currently[amountOfDisplayColumns] = {0, 0, 0, 0, 0, 0, 0, 0, 0, 0, 0, 0, 0, 0, 0, 0, 0, 0, 0, 0, 0, 0, 0, 0, 0};
uint8_t myBuffer[bufferSize] = {0, 0, 0, 0, 0, 0}; //prvy element bufferu je vzdy prazdny stlpec (why?) (tak riesime mezderu mezdi znakmi)
uint8_t messageSize = 0;
//mozno este casem aj hore-dole buffer na posuvanie hore-dole
unsigned long timeBetweenShifts = 40;
void setBuffer(uint8_t newuint8_t)    //sets a new uint8_character into buffer
{
  for(uint8_t x = 0; x < 5; x++)
  {
    myBuffer[x] = lookup[newuint8_t][x];
  }
  bufferRunner = 0;
}

void advanceBuffer()
{
  if(message[messageRunner] == '\0')
    {
      needsInput = true;
      setBuffer(" ");
    }
  else
  {
    setBuffer(message[messageRunner++]);
  }
}


void makeBufferEmpty()
{
  for (uint8_t x = 0; x < bufferSize; x++)
  {
    myBuffer[x] = 0;
  }
}

void makeCurrentEmpty()
{
  for(uint8_t x = 0; x < amountOfDisplayColumns ; x++)
   {
    currently[x]=0;
   }
}


void shiftLeft()    //shifts currently displaying left
{
  for(int x = amountOfDisplayColumns-1; x > 0; x--)
  {
    currently[x] = currently[x-1];    //true shift
  }

  if(bufferRunner == bufferSize)   //refresh buffer if needed
  {
    advanceBuffer();
  }
  currently[0] = myBuffer[bufferRunner++];  //add new column z buffera
  //Serial.print("Shoft ");
  //Serial.println(millis());
}



/*void display5uint8_t(uint8_t a, uint8_t b, uint8_t c, uint8_t d, uint8_t e, unsingned long time) //Displays 5 uint8_tacters, no shifting, prolly will be used for special smileys, time in milliseconds
{
  uint8_t local[15];
  for(int x = 0; x < 5; x++)
  {
    local[x] = lookup[a][x];
  }

  for(int x = 0; x < 5; x++)
  {
    local[x+5] = lookup[b][x];
  }

  for(int x = 0; x < 5; x++)
  {
    local[x+10] = lookup[c][x];
  }
  for(int x = 0; x < 100; x++)
  {
     displayArray(local);
  }
  Serial.println("TOPKEK");
}
*/


void randomize()
{
  for(uint8_t x = 0; x < amountOfDisplayColumns; x++)
  {
    currently[x] = random(0, 255);
  }

}
uint8_t scream[] = {'A', 'A', 'A', 'A', 'A', 'A', 'A', 'A', 'A', 'A', 'A', 'A', 'A', 'A', 'A', 'A', 'A', 'A', ' ',' ', ' ', ' ', '\0'};
uint8_t allLit[] = {10, 10, 10, 10, 10, 10, 10, 10, 10, 10, 10, 10, 10, 10, 10, 10, 10, 10, '\0'};
uint8_t fox[49] = {'T', 'H', 'E', ' ', 'Q', 'U', 'I', 'C', 'K', ' ',
 'B', 'R', 'O', 'W', 'N', ' ', 'F', 'O', 'X', ' ',
 'J', 'U', 'M', 'P', 'S', ' ', 'O', 'V', 'E', 'R',
 ' ', 'T', 'H', 'E', ' ', 'L', 'A', 'Z', 'Y', ' ',
 'D', 'O', 'G', ' ', ' ', ' ', ' ', ' ', ' ', };

 uint8_t B[5] = {'B', ' ', ' ', ' ', ' '};

 SoftwareSerial myBluetooth(7,6);//rx,tx

void getInput()
{

  for(uint8_t x = 0; x < 100; x++) message[x] = 0;
  /*for(uint8_t x = 0; x < 35; x++)
  message[x]= scream[x];*/
  /*for(uint8_t x = 0; x < 19; x++)
  message[x]= allLit[x];*/
  /*for(uint8_t x = 0; x < 43; x++)
  {
    message[x] = fox[x];
  }*/
  /*for(int x = 0; x < 49; x++)
  message[x]=fox[x];*/

  Serial.println("Wating");
  myBluetooth.println("Wating");
  while(myBluetooth.available()<1){delay(10);}

  //delayAmount=1;

  messageRunner = 0;

  while(myBluetooth.available()>0)
  {
    message[messageRunner++] = myBluetooth.read();
    delay(10);
  }

  for(int x =0; x < amountOfDisplays; x++) //add extra spaces, so that whole text moves away
  {
      message[messageRunner++] = ' ';
  }

  message[messageRunner++] = '\0'; //add ending symbol
  messageSize = messageRunner-1;
  messageRunner = 0;

  for (int x = 0; x < messageSize; x++) myBluetooth.print(message[x]);
  myBluetooth.println();
  needsInput = false;
  messageRunner = 0;
  setBuffer(message[messageRunner++]);
  bufferRunner=0;
  Serial.println("HaZ iNpUt   UwU");
  myBluetooth.println("HaZ iNpUt UwU");
  needsInput = false;
  if(message[0] == '/' && message[1] == 's')
    {
      timeBetweenShifts = (message[2]-'0')*50;
    if(timeBetweenShifts < 10) timeBetweenShifts = 100;
    if(timeBetweenShifts > 999) timeBetweenShifts = 900;
    needsInput = true;
    myBluetooth.print("Speed changed to");
    myBluetooth.println(timeBetweenShifts);
    }

}

void displayArray(const uint8_t toDisplay[])
{
  startColumns();
  for(int x =0; x < amountOfDisplayColumns; x++)
  {

    SPI.transfer(toDisplay[x]); //to be polished, '~' was just a dirty fix
    sendRowLatch();

    if(x > 0)
    {
      sendColClock();
    }


    enableAllOutputs(1);
    delayMicroseconds(300);                 //WAIT TO DISPLAY STUFF
    //delay(100);
    enableAllOutputs(0);
  }

}

void calculateNext()
{

  if(needsInput)
  {
    getInput();

  }
  else
  {
    shiftLeft();
  }
  //randomize();
}

void displayOnce()
{
  displayArray(currently);        //display the shifted array
}

/*void displayMessage(uint8_t mes[])
{
  calculateNext();
  displayOnce();
}
*/
uint8_t abeceda[] = {'A', 'B', 'E', 'C', 'E', 'D', 'A', ' ', 'Z', 'J', 'E', 'D', 'L', 'A', ' ', 'D', 'E', 'D', 'A', ' ', ' ', ' ', ' '};
uint8_t nudes[]={'S', 'E', 'N', 'D', ' ', 'N', 'U', 'D', 'E', 'S', ' ', ' '};
uint8_t hardMessage[] = {78, 73, 69, 67, 79, 32, 83, 84, 82, 65, 83, 73, 68, 69, 76, 78, 69, 32, 32, 32, 0};

//uint8_t allLit[] = {10, 10, 10, 10, 10, 10, 10, 10, 10, 10, 10, 10, 10, 10, 10, 10, 10, 10, '\0'};


/*void myDelay()
{
  digitalWrite(13, HIGH);
  for(int x = 0; x < 100000; x++){}
  digitalWrite(13, LOW);
}
*/

void setup()
{
  for(int x= 2; x < 19; x++)
    {
      pinMode(x, OUTPUT);
      digitalWrite(x, LOW);
    }
    //digitalWrite(uint8_t, uint8_t)
    pinMode(7, INPUT);
    //pinMode(5, INPUT);
    pinMode(A0, OUTPUT);
    pinMode(A1, OUTPUT);
    pinMode(A2, OUTPUT);
    pinMode(A3, OUTPUT);
    pinMode(A4, OUTPUT);
  //randomSeed(analogRead(A1));
  //pinMode(2, INPUT_PULLUP);
  //attachInterrupt(digitalPinToInterrupt(2), myDelay, FALLING);
  Serial.begin(9600);
  myBluetooth.begin(9600);
  resetRegisters();
  enableAllOutputs(true);
  needsInput = true;
  Serial.println("Probably Initialised Succesfully, can't really tell...");

  SPI.begin();
  SPI.beginTransaction(SPISettings(SPI_CLOCK_DIV4, LSBFIRST, SPI_MODE0));
  pinMode(2, INPUT);
  pinMode(4, OUTPUT);
  digitalWrite(4, HIGH);

}

unsigned long lastTime = 0;

int rawDelay;
void loop()
{
  if(millis() > lastTime + timeBetweenShifts)
  {
    lastTime = millis();
    if(needsInput)
    {
      Serial.println("Cau I HaZ InPut? OwO UwO");
      myBluetooth.println("Can I HaZ InPut? UwO");
    }
    calculateNext();
  }
  displayOnce();
}
